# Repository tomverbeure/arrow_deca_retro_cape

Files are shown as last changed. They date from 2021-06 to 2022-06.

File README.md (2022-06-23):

# DECA Retro Cape

**IMPORTANT: this PCB is unusuable due to an incorrect spacing between the connectors!!!**

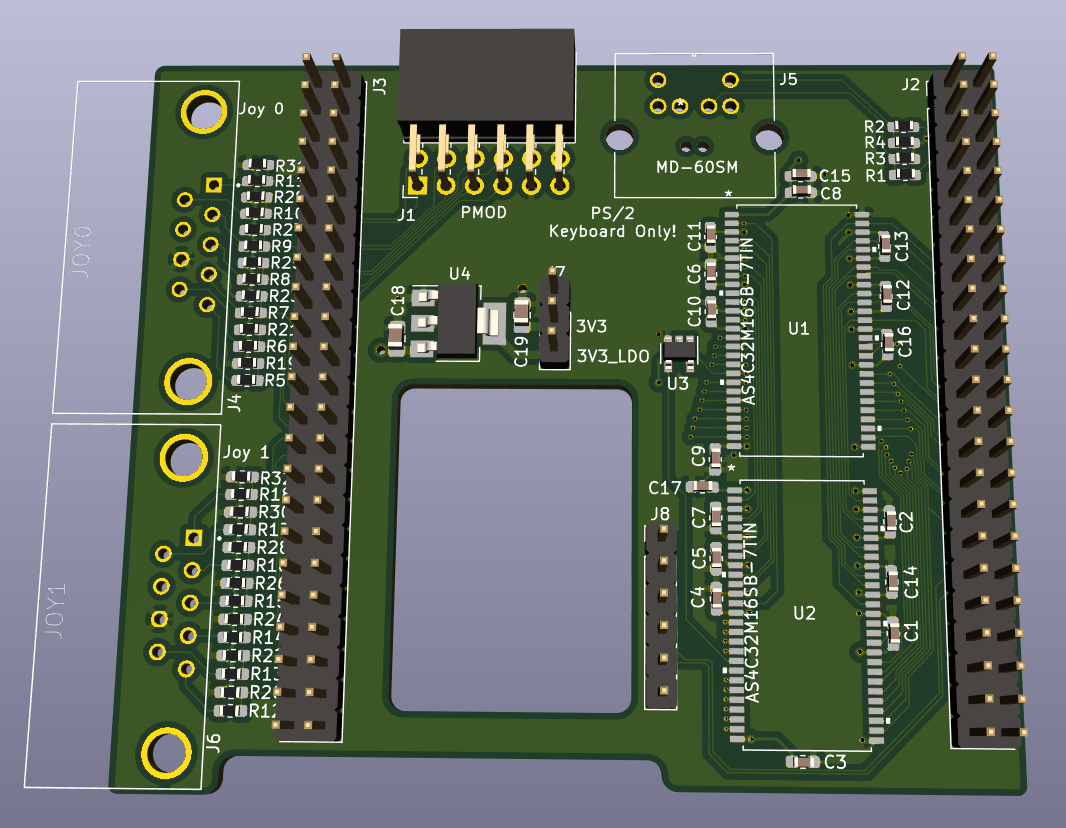
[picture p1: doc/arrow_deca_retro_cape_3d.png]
Arrow DECA Retro Cape 3D
 

This project is a plug-in PCB for the Arrow DECA FPGA board to extend it with the
following features:

* 2 16Mx16 SDRAMs

    Compatible with the Mister SDRAM xsds. 

* 1 PS/2 Keyboard interface

    Mouse will not work, because it's a unidirectional interface.

* 2 Atari Joystick DB9 ports 

* 1 general purupose PMOD connector

Like the SDRAM xsds board, I'm using a 5V to 3.3V LDO instead of relying on the 3V3
supply of the DECA board itself.

**Status: sent to JLCPCB. Not tested...**

# Various Notes

The information below is not always relevant, but just stuff that I gathered while
working on this PCB...

## Different Mister SDRAM Versions

Mister Addons are all designed with Altium. If you don't have a license, you can use
the Altium on-line viewer to check out schematics and PCB. I've made a screenshot of some
of them.

There are 2 main variants of SDRAM models:

1. With dedicated DQML/DQMH/CKE pins
1. With DQML/DQMH connected to A11/A12 and CKE strapped to 1.

    A11 and A12 are only used during RAS cycles, not during CAS cycles. Conversely, 
    DQML and DQMH are only during CAS cycles. So you can multi-purpose 2 pins, and thus
    save 2 pins on the connector.

    By strapping CKE to high, you can't use certain low power modes of the SDRAM, but
    that's not a major issue for a Mister-like design. However, the SDRAM datasheet
    also says that CKE must be low which VDD is being powered up, so that might
    be a violation depending on the overall power sequencing.

Because the second variant requires 3 pins less on a connector, it's now the most used option.

* [SDRAM SRAM v1.3](https://github.com/MiSTer-devel/Hardware_MiSTer/tree/master/Addons/SDRAM_SRAM)

    * 1x 16x16Mb SDRAM and 1x SRAM 8x2Mb SRAM.
    * Uses CKE to select between SDRAM and SRAM: CKE is connected SRAM.nCE.
    * Variant 1 connector.
    * Not used very often.

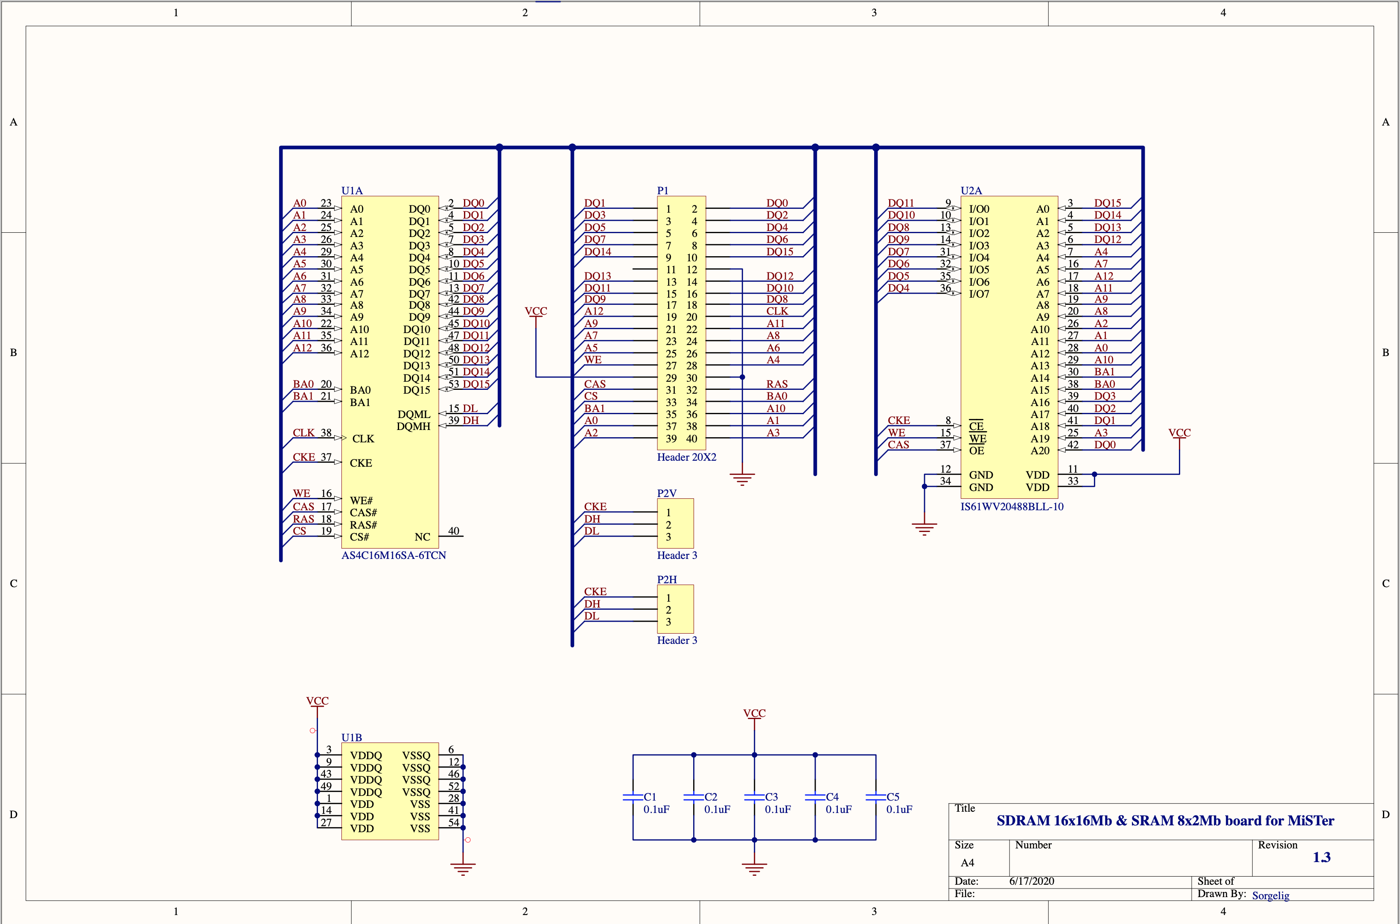
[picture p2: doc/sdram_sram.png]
SDRAM SRAM schematic
    

* [SDRAM uni 3.2U](https://github.com/MiSTer-devel/Hardware_MiSTer/tree/master/Addons/SDRAM_uni)

    * 1x 16x16Mb SDRAM
    * Variant 1 connector.

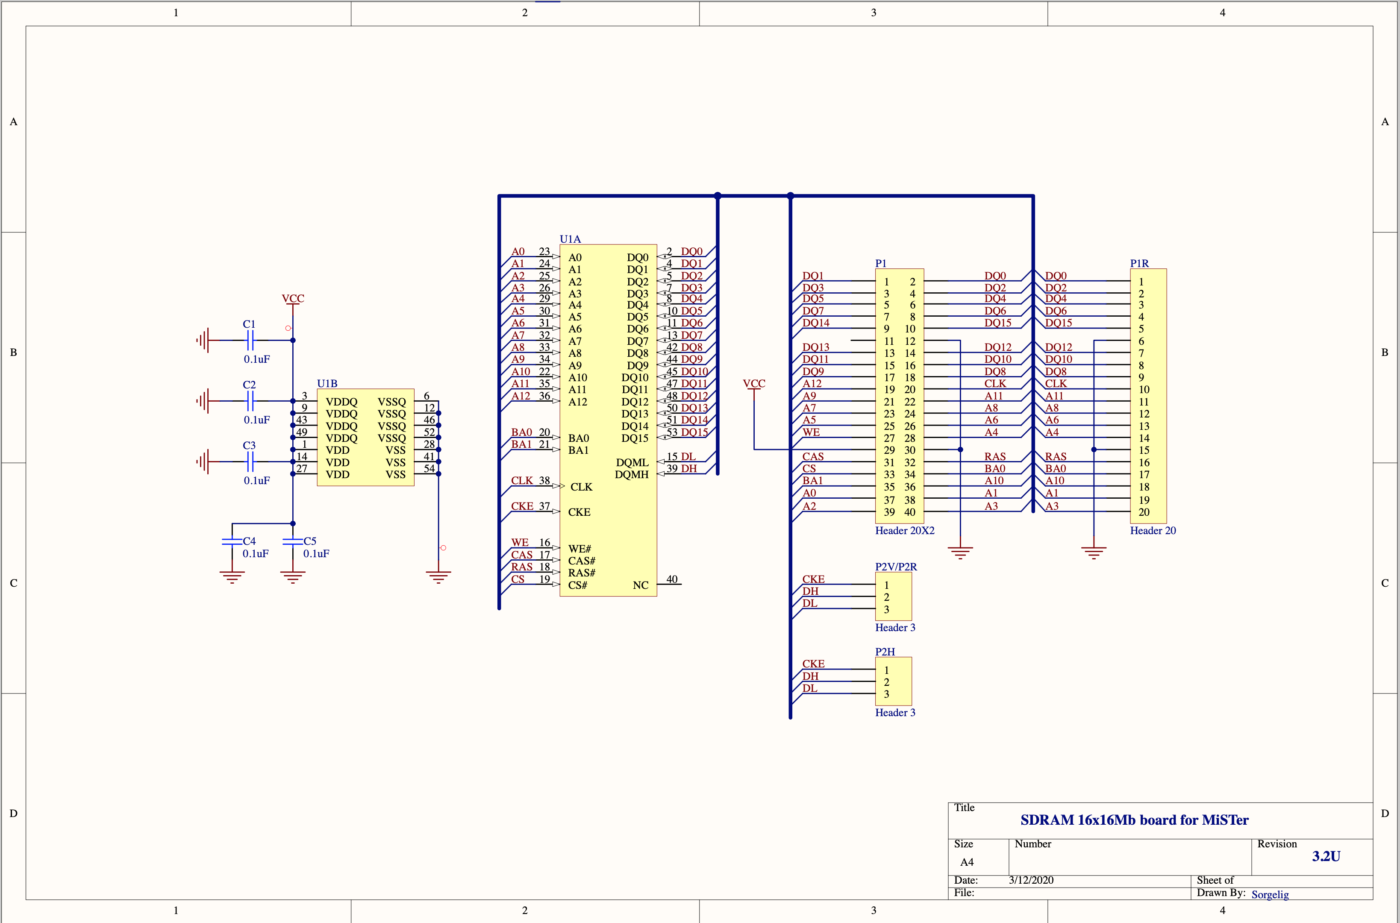
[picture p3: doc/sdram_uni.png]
SDRAM uni schematic
    

* [SDRAM xs 2.2](https://github.com/MiSTer-devel/Hardware_MiSTer/tree/master/Addons/SDRAM_xs)

    * Extra Slim (more compact than uni)
    * 1x 16x16Mb SDRAM
    * Variant 2 connector.

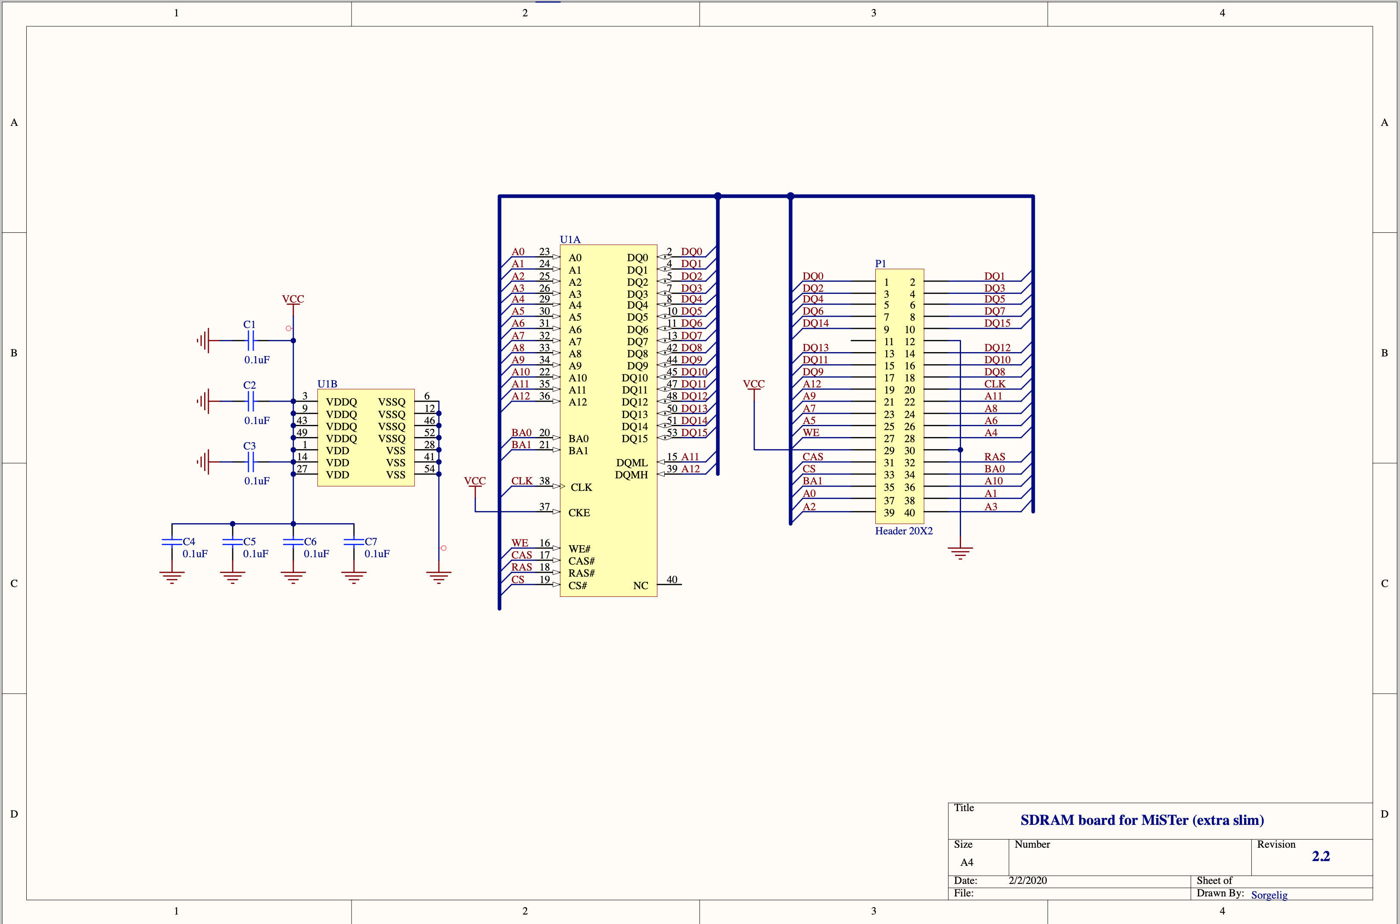
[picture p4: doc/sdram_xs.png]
SDRAM xs schematic
    

* [SDRAM xsd 2.5](https://github.com/MiSTer-devel/Hardware_MiSTer/tree/master/Addons/SDRAM_xsd)

    * Extra Slim, Dual-chip
    * 2x 16x16Mb SDRAM
    * All pins are shared between the 2 devices (so no double BW).
    * Variant 2 connector.
    * nCS for SDRAM2 is inverted version nCS of SDRAM1.

        This works because SDRAMs has 2 NOP commands: when nCS is high, all commands to the
        SDRAM are NOP, and when nCS is low, there's still 1 combination that's also a NOP.

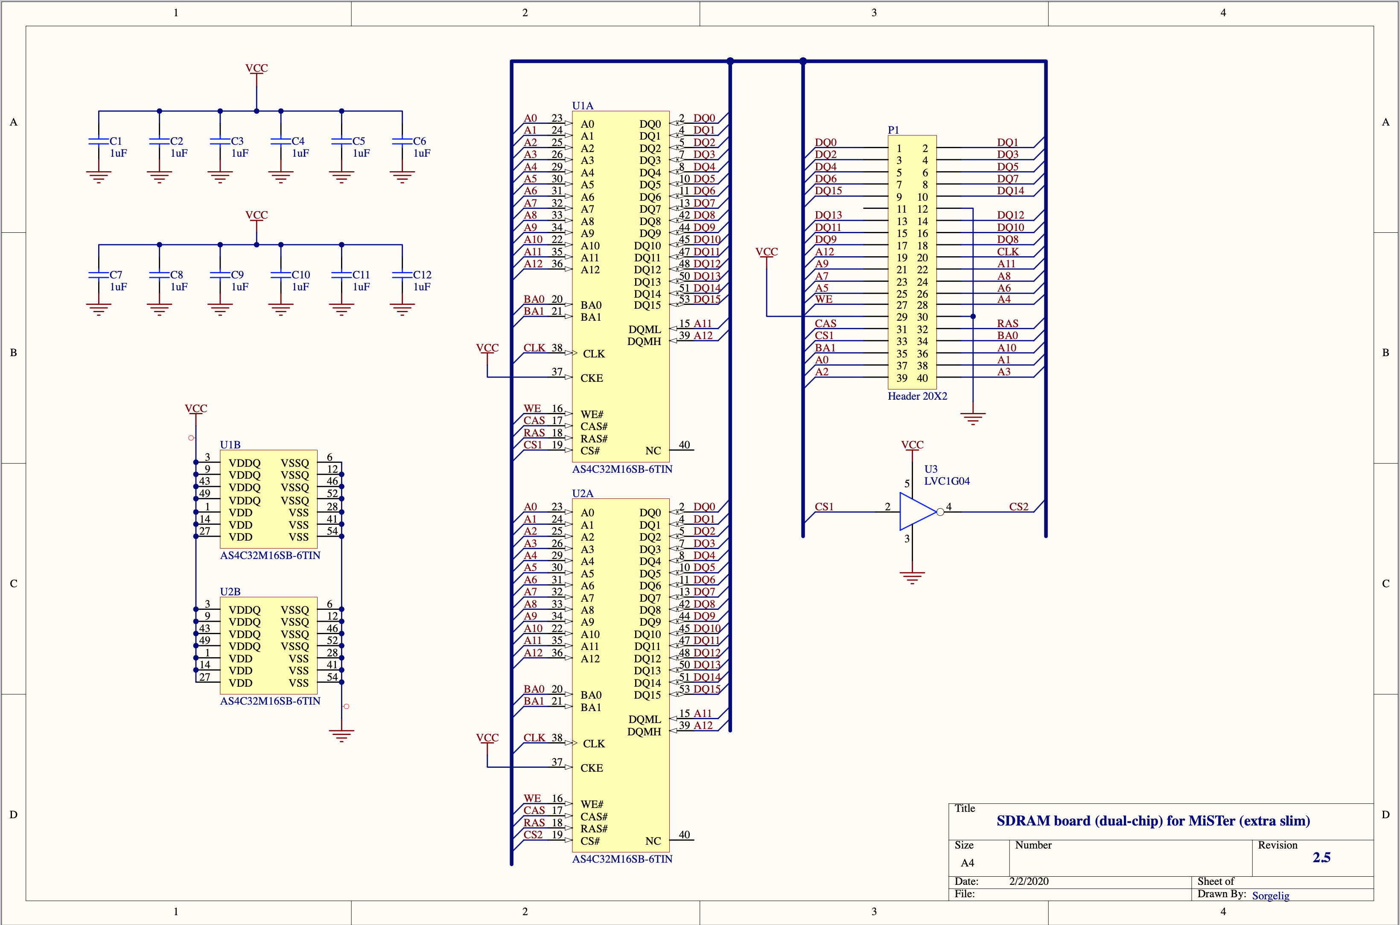
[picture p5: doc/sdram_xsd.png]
SDRAM xsd schematic
    

* [SDRAM xsds 2.9](https://github.com/MiSTer-devel/Hardware_MiSTer/tree/master/Addons/SDRAM_xsds)

    * Extra Slim, Dual-chip
    * Logically identical to SDRAM xsd.
    * Uses DE10-Nano GPIO1 pin 11 (5V) in combination with an 
      [LM1117-3V3 LDO](https://www.ti.com/lit/ds/symlink/lm1117.pdf) to power the SDRAMs for
      higher noise resistance, instead of using GPIO1 pin 29 (3V3), which was used in all
      previous designs.

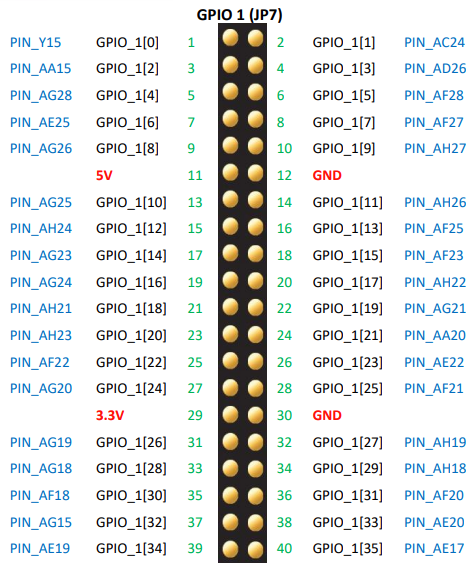
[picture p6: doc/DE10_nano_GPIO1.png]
DE10-Nano GPIO1 connector
      

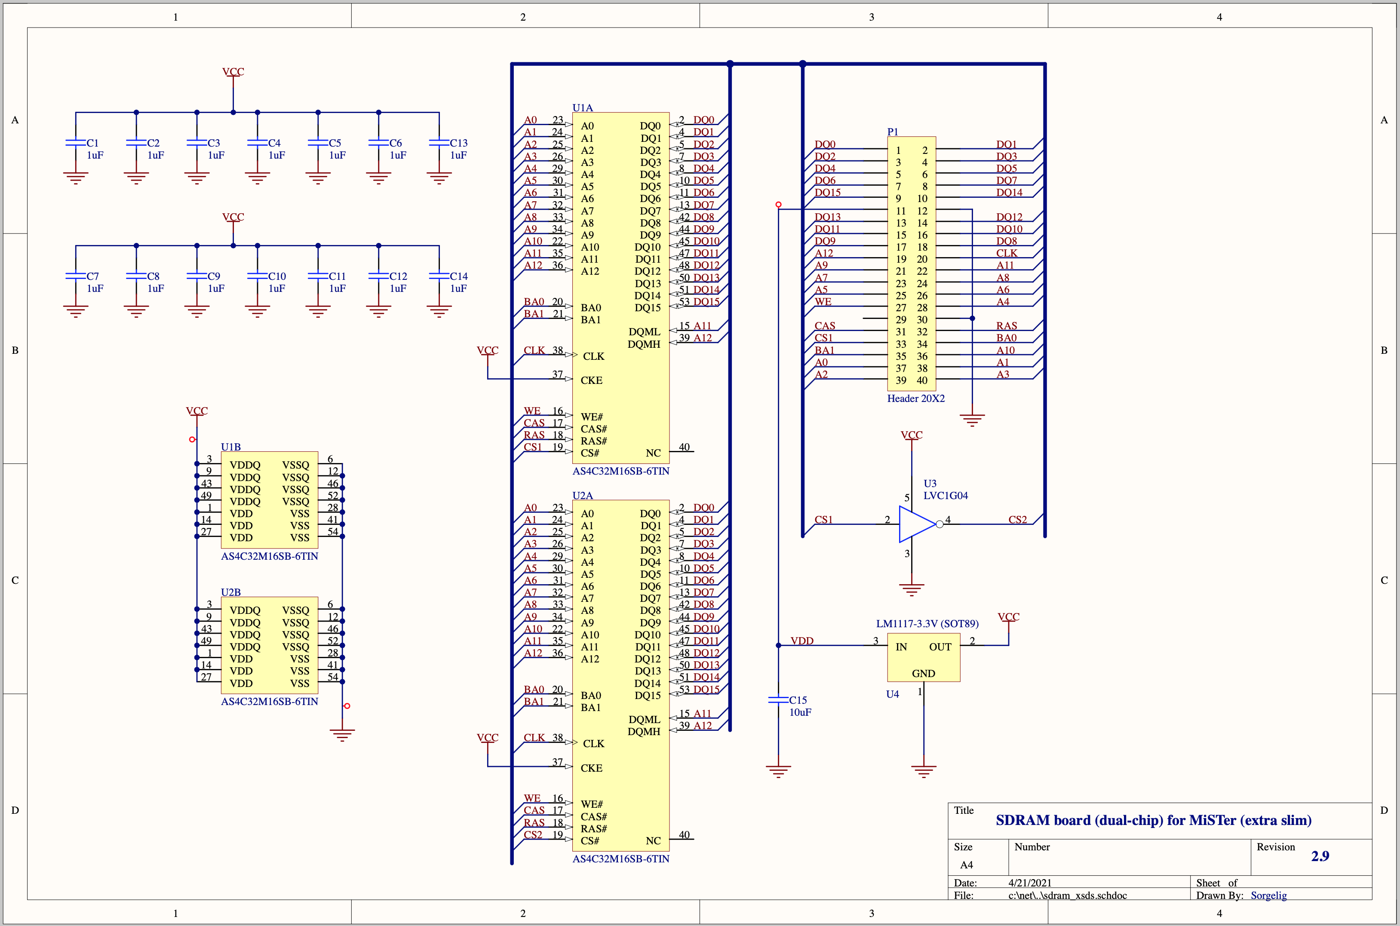
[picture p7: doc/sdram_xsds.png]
SDRAM xsds schematic
    

## Ferrite Bead Info

* [Analog Devices - Ferrite Beads Demystified](https://www.analog.com/media/en/technical-documentation/application-notes/AN-1368.pdf)
* [Choosing and Using Ferrite Beads](https://www.allaboutcircuits.com/technical-articles/choosing-and-using-ferrite-beads/)
* [TI - High-Speed DSP Systems Design- Reference Guide](https://www.ti.com.cn/cn/lit/ug/spru889/spru889.pdf)
* [Altium - Everything You Need to Know about Ferrite Beads](https://resources.altium.com/p/everything-you-need-to-know-about-ferrite-beads)

    Argues against its use.

## References

* [Hardware addons for MiSTer - SDR SDRAM daughter board](https://github.com/MiSTer-devel/Hardware_MiSTer#sdr-sdram-daughter-board)

    Discusses different board versions and SDRAM types, clock speeds.

    This repo also contains the Altium designs for the different add-ons. They can be viewed with the
    [Altium Online Schematic and PCB Viewer](https://www.altium.com/viewer/).

* [Addon Board Repo on GitHub](https://github.com/MiSTer-devel/Hardware_MiSTer/tree/master/Addons)

* [SDRAM Board Wiki](https://github.com/MiSTer-devel/Main_MiSTer/wiki/SDRAM-Board)

* [AS4C32M16SB-6TIN datasheet](https://www.mouser.com/datasheet/2/12/512M%20SDRAM_%20B%20die_AS4C32M16SB-7TCN-7TIN-6TIN_Rev%201-1265391.pdf)

    * [AS4C32M16SB-6TIN on Digikey](https://www.digikey.com/en/products/detail/alliance-memory-inc/AS4C32M16SB-6TIN/6716555)
    * [AS4C32M16SB-6TIN on Mouser](https://www.mouser.com/ProductDetail/913-AS4C32M16SB-6TIN)

* [Altium Online Schematic and PCB Viewer](https://www.altium.com/viewer/)

* [Mister dual-SDRAM Reliability discussion](https://misterfpga.org/viewtopic.php?t=1727)
* [SDRAM Termination discussion](https://www.electronicspoint.com/forums/threads/sdram-clock-termination.19018/)
* [SDRAM Termination discussion](https://designhelp.fedevel.com/forum/test/pcb-layout/82-sdr-sdram-layout-recommendations)
* [SDRAM Termination question on Stackexchange](https://electronics.stackexchange.com/questions/38718/termination-resistors-are-they-needed)
* [Discussion about SDRAM xsds v2.9](https://misterfpga.org/viewtopic.php?t=2480)

* [Waveshare VGA PS/2 Board](https://www.waveshare.com/vga-ps2-board.htm)

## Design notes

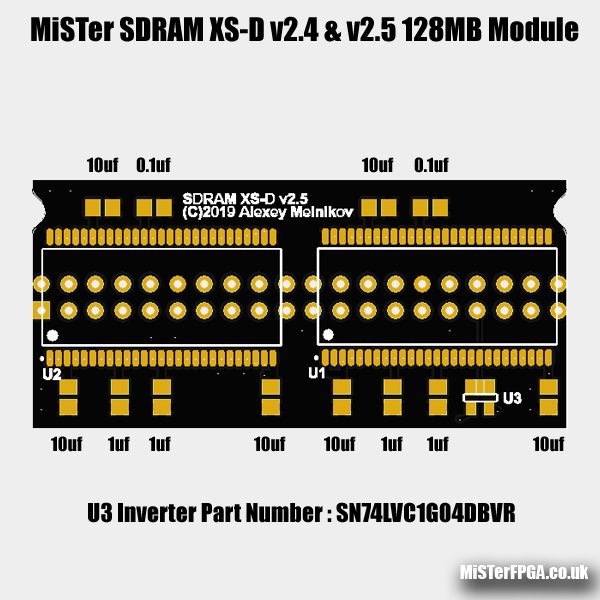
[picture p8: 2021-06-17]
MiSTer-FPGA-128MB-SDRAM-Capacitor-Values.png

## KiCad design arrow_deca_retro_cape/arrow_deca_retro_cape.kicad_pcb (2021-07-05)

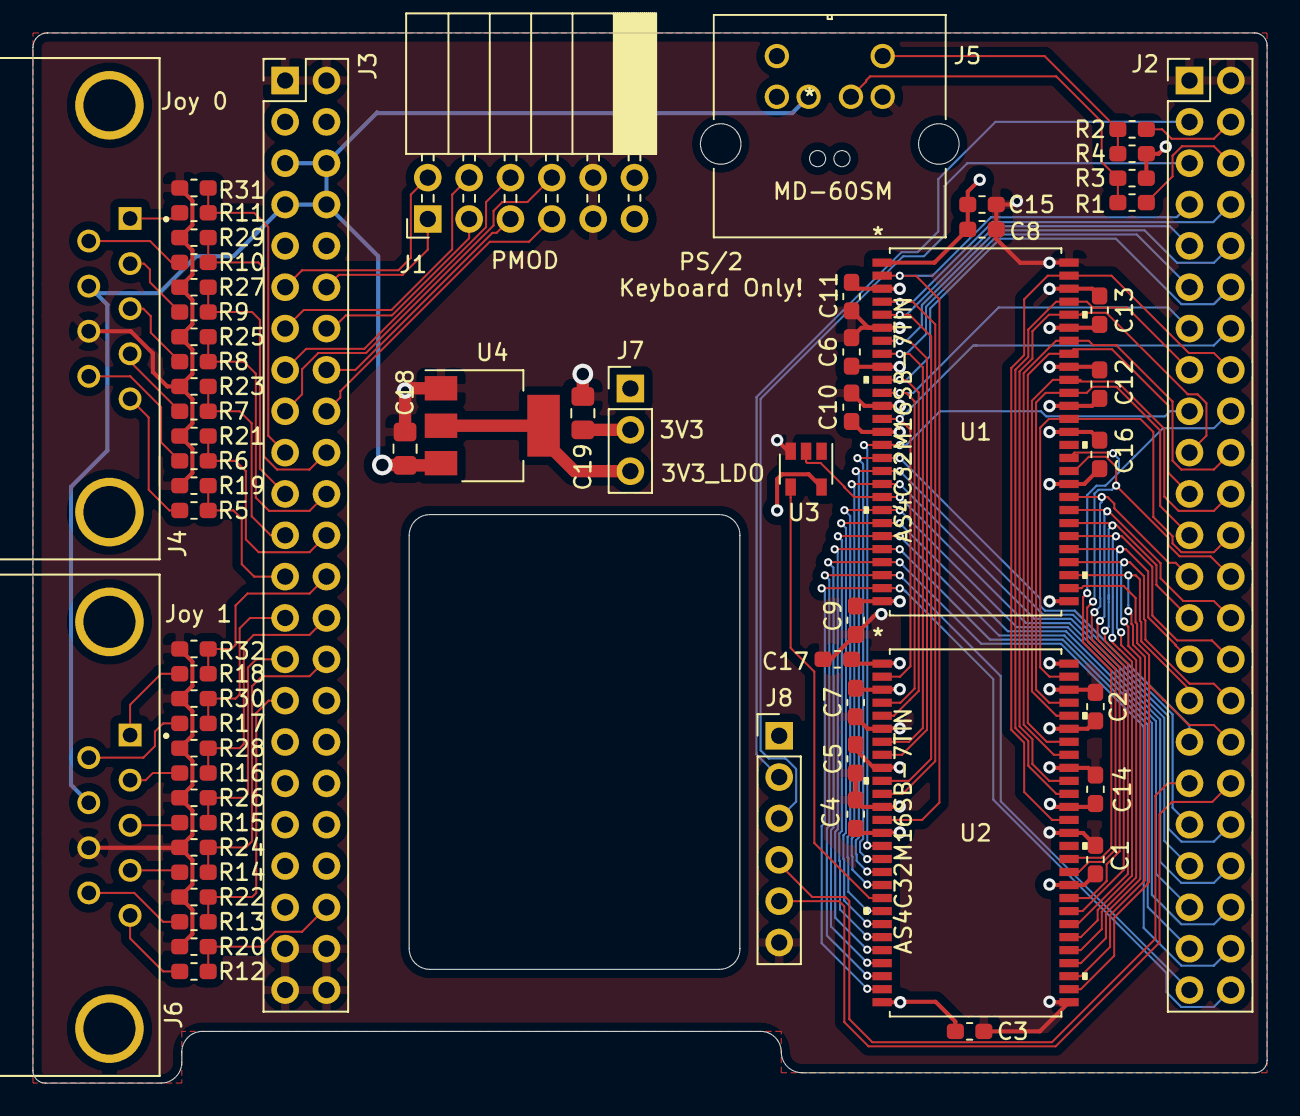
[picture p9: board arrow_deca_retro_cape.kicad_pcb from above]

Board: 4 copper layers, 75.8 x 64.5 mm, 63 parts (0 on the bottom side), 88 nets.

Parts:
C1, C2, C3, C4, C5, C6, C7, C8, C9, C10, C11, C12, C13, C14, C15, C16, C17: 1uF; C_0603_1608Metric_Pad1.05x0.95mm_HandSolder
C18: 10uF; C_0805_2012Metric_Pad1.15x1.40mm_HandSolder
C19: 100uF; C_0805_2012Metric_Pad1.15x1.40mm_HandSolder
J1: PMOD; PMOD_Female_Horizontal
J2: P8_Male; PinHeader_2x23_P2.54mm_Vertical
J3: P9_Male; PinHeader_2x23_P2.54mm_Vertical
J4: JOY0; TE_1-1634580-2
J5: MD-60SM
J6: JOY1; TE_1-1634580-2
J7: Conn_01x03; PinHeader_1x03_P2.54mm_Vertical
J8: Conn_01x06; PinHeader_1x06_P2.54mm_Vertical
R1, R2: 1K; R_0603_1608Metric_Pad1.05x0.95mm_HandSolder
R3, R4: 10K; R_0603_1608Metric_Pad1.05x0.95mm_HandSolder
R5, R6, R7, R8, R9, R10, R11, R12, R13, R14, R15, R16, R17, R18: 2K; R_0603_1608Metric_Pad1.05x0.95mm_HandSolder
R19, R20, R21, R22, R23, R24, R25, R26, R27, R28, R29, R30, R31, R32: 5K; R_0603_1608Metric_Pad1.05x0.95mm_HandSolder
U1, U2: AS4C32M16SB-7TIN
U3: 74LVC1G04; SOT-23-5
U4: LM1117-3.3; SOT-223-3_TabPin2

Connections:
+3.3VP: J3.3, J3.4, J7.1
+3V3: C1.1, C2.1, C3.1, C4.1, C5.1, C6.1, C7.1, C8.1, C9.1, C10.1, C11.1, C12.1, C13.1, C14.1, C15.1, C16.1, C17.1, C19.1, J1.6, J1.12, J7.2, J8.1, R3.1, R4.1, U1.1, U1.3, U1.9, U1.14, U1.27, U1.37, U1.43, U1.49, U2.1, U2.3, U2.9, U2.14, U2.27, U2.37, U2.43, U2.49, U3.5
+5V: C18.1, J3.5, J3.6, J3.7, J3.8, J4.7, J5.2, J6.7, U4.3
/3V3_LDO: J7.3, U4.2
/A0: J2.43, U1.23, U2.23
/A1: J2.44, U1.24, U2.24
/A2: J2.45, U1.25, U2.25
/A3: J2.46, U1.26, U2.26
/A4: J2.34, U1.29, U2.29
/A5: J2.31, U1.30, U2.30
/A6: J2.32, U1.31, U2.31
/A7: J2.29, U1.32, U2.32
/A8: J2.30, U1.33, U2.33
/A9: J2.27, U1.34, U2.34
/A10: J2.42, U1.22, U2.22
/A11: J2.28, U1.35, U2.35
/A12: J2.25, U1.36, U2.36
/BA0: J2.40, U1.20, U2.20
/BA1: J2.41, U1.21, U2.21
/CLK: J2.26, U1.38, U2.38
/DQ0: J2.7, U1.2, U2.13
/DQ1: J2.8, U1.4, U2.11
/DQ2: J2.9, U1.5, U2.10
/DQ3: J2.10, U1.7, U2.8
/DQ4: J2.11, U1.8, U2.7
/DQ5: J2.12, U1.10, U2.5
/DQ6: J2.13, U1.11, U2.4
/DQ7: J2.14, U1.13, U2.2
/DQ8: J2.24, U1.42, U2.53
/DQ9: J2.23, U1.44, U2.51
/DQ10: J2.22, U1.45, U2.50
/DQ11: J2.21, U1.47, U2.48
/DQ12: J2.20, U1.48, U2.47
/DQ13: J2.19, U1.50, U2.45
/DQ14: J2.15, U1.51, U2.44
/DQ15: J2.16, U1.53, U2.42
/GPIO0: J2.3, J8.2
/GPIO1: J2.5, J8.3
/GPIO2: J2.35, J8.4
/GPIO3: J2.36, J8.5
/J0_DOWN: J3.21, R9.1, R27.1
/J0_LEFT: J3.22, R8.1, R25.1
/J0_PADDLE_A: J3.24, R6.1, R21.1
/J0_PADDLE_B: J3.25, R5.1, R19.1
/J0_RIGHT: J3.23, R7.1, R23.1
/J0_TRIGGER: J3.20, R10.1, R29.1
/J0_UP: J3.19, R11.1, R31.1
/J1_DOWN: J3.28, R16.1, R28.1
/J1_LEFT: J3.29, R15.1, R26.1
/J1_PADDLE_A: J3.31, R13.1, R22.1
/J1_PADDLE_B: J3.42, R12.1, R20.1
/J1_RIGHT: J3.30, R14.1, R24.1
/J1_TRIGGER: J3.27, R17.1, R30.1
/J1_UP: J3.26, R18.1, R32.1
/JOY0_DOWN: J4.2, R9.2
/JOY0_LEFT: J4.3, R8.2
/JOY0_PADDLE_A: J4.9, R6.2
/JOY0_PADDLE_B: J4.5, R5.2
/JOY0_RIGHT: J4.4, R7.2
/JOY0_TRIGGER: J4.6, R10.2
/JOY0_UP: J4.1, R11.2
/JOY1_DOWN: J6.2, R16.2
/JOY1_LEFT: J6.3, R15.2
/JOY1_PADDLE_A: J6.9, R13.2
/JOY1_PADDLE_B: J6.5, R12.2
/JOY1_RIGHT: J6.4, R14.2
/JOY1_TRIGGER: J6.6, R17.2
/JOY1_UP: J6.1, R18.2
/LDQM: J2.17, U1.15, U2.15
/PMOD_D0: J1.10, J3.17
/PMOD_D1: J1.4, J3.18
/PMOD_D2: J1.9, J3.15
/PMOD_D3: J1.3, J3.16
/PMOD_D4: J1.8, J3.13
/PMOD_D5: J1.2, J3.14
/PMOD_D6: J1.7, J3.11
/PMOD_D7: J1.1, J3.12
/PS2_CLK: J2.4, R2.2
/PS2_CLK_5V: J5.6, R2.1, R4.2
/PS2_DATA: J2.6, R1.2
/PS2_DATA_5V: J5.1, R1.1, R3.2
/UDQM: J2.18, U1.39, U2.39
/nCAS: J2.37, U1.17, U2.17
/nCS0: J2.39, U1.19, U3.2
/nCS1: U2.19, U3.4
/nRAS: J2.38, U1.18, U2.18
/nWE: J2.33, U1.16, U2.16
GND: C1.2, C2.2, C3.2, C4.2, C5.2, C6.2, C7.2, C8.2, C9.2, C10.2, C11.2, C12.2, C13.2, C14.2, C15.2, C16.2, C17.2, C18.2, C19.2, J1.5, J1.11, J2.1, J2.2, J3.1, J3.2, J3.43, J3.44, J3.45, J3.46, J4.8, J5.5, J6.8, J8.6, R19.2, R20.2, R21.2, R22.2, R23.2, R24.2, R25.2, R26.2, R27.2, R28.2, R29.2, R30.2, R31.2, R32.2, U1.6, U1.12, U1.28, U1.41, U1.46, U1.52, U1.54, U2.6, U2.12, U2.28, U2.41, U2.46, U2.52, U2.54, U3.3, U4.1

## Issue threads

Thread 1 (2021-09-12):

BBB connectors spacing wrong

somhi, 2021-09-12:
Hi Tom,

I saw in twitter there was an error in the BBB connectors spacing. Have you already send an updated design to PCB manufacturers?

Cheers

tomverbeure, 2021-09-12:
I have not. One day…

somhi, 2021-09-12:
One day we will also make a cape for it.

Community and cores started to grow at
https://github.com/DECAfpga, but then aliexpress sellers came and Arrow stocks are nearly gone.
I've found around 1300 units at aliexpress at sell price +$280

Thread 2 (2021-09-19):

IO Bank Voltages

somhi, 2021-09-19:
I've set up Bank Voltages as your post and this Blink example.

Working with an SDRAM connected to P8 memtest is giving lots of error with GPIO pins at 3V3. Runs Ok at 100 MHz.
SDRAM is working OK at 2V5 at 160 MHz.

Any clue to set it up at 3V3 as it should, but avoid that lots of errors?
I've tested CURRENT_STRENGTH_NEW 4 mA and "MAXIMUM CURRENT" with no improvement.

Letting it to 2V5 seems the best solution though.

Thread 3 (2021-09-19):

Pin 28 location PIN_AA13 slower than other P8 GPIO pins

somhi, 2021-09-19:
Just let you know the latest findings running the sdram mister module connected directly to P8 connector

Pin 28 used for SDRAM_ADDR[11]  has a large output delay compared to the rest of pins.
That pin is connected to VREF of Bank4 but used as regular IO.

" When VREF pins are used as I/O, they have higher capacitance than regular I/O pins which will slow the edge rates and affect I/O timing." - https://www.intel.com/content/dam/www/programmable/us/en/pdfs/literature/dp/cyclone3/pcg-01003.pdf

According to Alastair @robinsonb5 that vref pin's not a huge problem, anyway - I don't think it'll be a barrier to running the SDRAM at 128MHz, which I think is the fastest it runs in "real" cores. But when making a cape it'd be worth avoiding that pin if we can.

somhi, 2021-09-19:
Haven't defined voltage for P8 GPIOs so they default to 2V5.  I've set up STRENGHT to 4 mA.
With that  SDRAM_ADDR[11] has a data delay of 7 ps whereas rest of address pins are at 2.7 ps
After defining  STRENGHT to maximum just for that specific pin data delay has reduced to 3.4 ps
So doesn't seem to be a major problem.

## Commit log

2021-06-16 Copy and rename pmod_cape -> retro_cape
    [arrow_deca_retro_cape.kicad_pcb, arrow_deca_retro_cape.sch]
2021-06-19 Starting to add VGA.
    [arrow_deca_retro_cape.kicad_pcb, arrow_deca_retro_cape.sch]
2021-07-03 Layout finished.
    [arrow_deca_retro_cape.kicad_pcb, arrow_deca_retro_cape.sch]
2021-07-05 rev1, sent to JLPCB.
    [arrow_deca_retro_cape-B_Cu.gbr, arrow_deca_retro_cape-B_Mask.gbr, arrow_deca_retro_cape-B_Paste.gbr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]

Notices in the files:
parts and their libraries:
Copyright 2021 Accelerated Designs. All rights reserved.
